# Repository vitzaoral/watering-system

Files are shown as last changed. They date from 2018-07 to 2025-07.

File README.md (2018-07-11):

# Watering system
IoT watering system based on ESP8266 Wemos D1 Mini. Use soil moisture sensors and temperature sensor, data are send to Blynk. Water level is checked by ultrasonic distance measuring module. Water pumps are controller by Blynk application manually, powered with 12V (at least 1A) via mosfet modules.
Project is free to use, coded in C++, created in Visual Code with [PlatfomIO IDE](http://docs.platformio.org/en/latest/ide/vscode.html).

> To build a project, you need to download all the necessary libraries and create the *settings.cpp* file in the src folder:
```c++
// Watering system project settings
struct Settings
{
    const char *ssid = "WIFI ssid";
    const char *password = "WIFI password";
    const char *blynkAuth = "blynkAuth";
};
```

### Currents list:
* [Wemos D1 Mini](https://www.aliexpress.com/item/D1-mini-V2-Mini-NodeMcu-4M-bytes-Lua-WIFI-Internet-of-Things-development-board-based-ESP8266/32681374223.html)
* [6x Soil Moisture Sensor](https://www.aliexpress.com/item/Smart-Electronics-Soil-Moisture-Hygrometer-Detection-Humidity-Sensor-Module-For-arduino-Development-Board-DIY-Robot-Smart/32562744759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)
* [2x 12V water pump](https://www.aliexpress.com/item/DC-12V-Hydroponics-Heating-Mattress-Food-Mdical-Super-Sound-off-Water-Cooling-Cycle-Brushless-Pressure-Boost/32813036499.html)
* [2x IRF520 MOS Driver Module](https://www.aliexpress.com/item/1PCS-0-24V-Top-Mosfet-Button-IRF520-MOS-Driver-Module-For-Arduino-MCU-ARM-Raspberry-pi/32722409551.html)
* [HC-SR04 ultrasonic distance measuring module](https://www.aliexpress.com/item/1pcs-Ultrasonic-Module-HC-SR04-Distance-Measuring-Transducer-Sensor-HC-SR04-HCSR04/32703532280.html)
* [74HC4051 Multiplexer](https://www.aliexpress.com/item/10PCS-LOT-CD4051BE-CD4051-4051BE-4051-DIP16-new-and-original-IC/32807746646.html)
* [GY-BME280-3-3 Temperature/Humidity/Presure sensor](https://www.aliexpress.com/item/1PCS-GY-BME280-3-3-precision-altimeter-atmospheric-pressure-BME280-sensor-module/32767969468.html)
* [7x9cm prototype circuit board](https://www.aliexpress.com/item/MCIGICM-5Pcs-DIY-Prototype-Paper-PCB-Universal-Experiment-Matrix-Circuit-Board-7x9cm-7-9/32350333672.html)
* [Plastic case](https://www.aliexpress.com/item/1-piece-158-90-60mm-IP65-waterproof-plastic-case-with-clear-cover-for-electronic-project-Housing/32812690691.html)
* [Temperature sensor box](https://www.aliexpress.com/item/szomk-plastic-humidity-sensor-project-box-2-pcs-84-27-16mm-diy-wall-mounting-plastic-junction/32586666805.html)

### Schema:
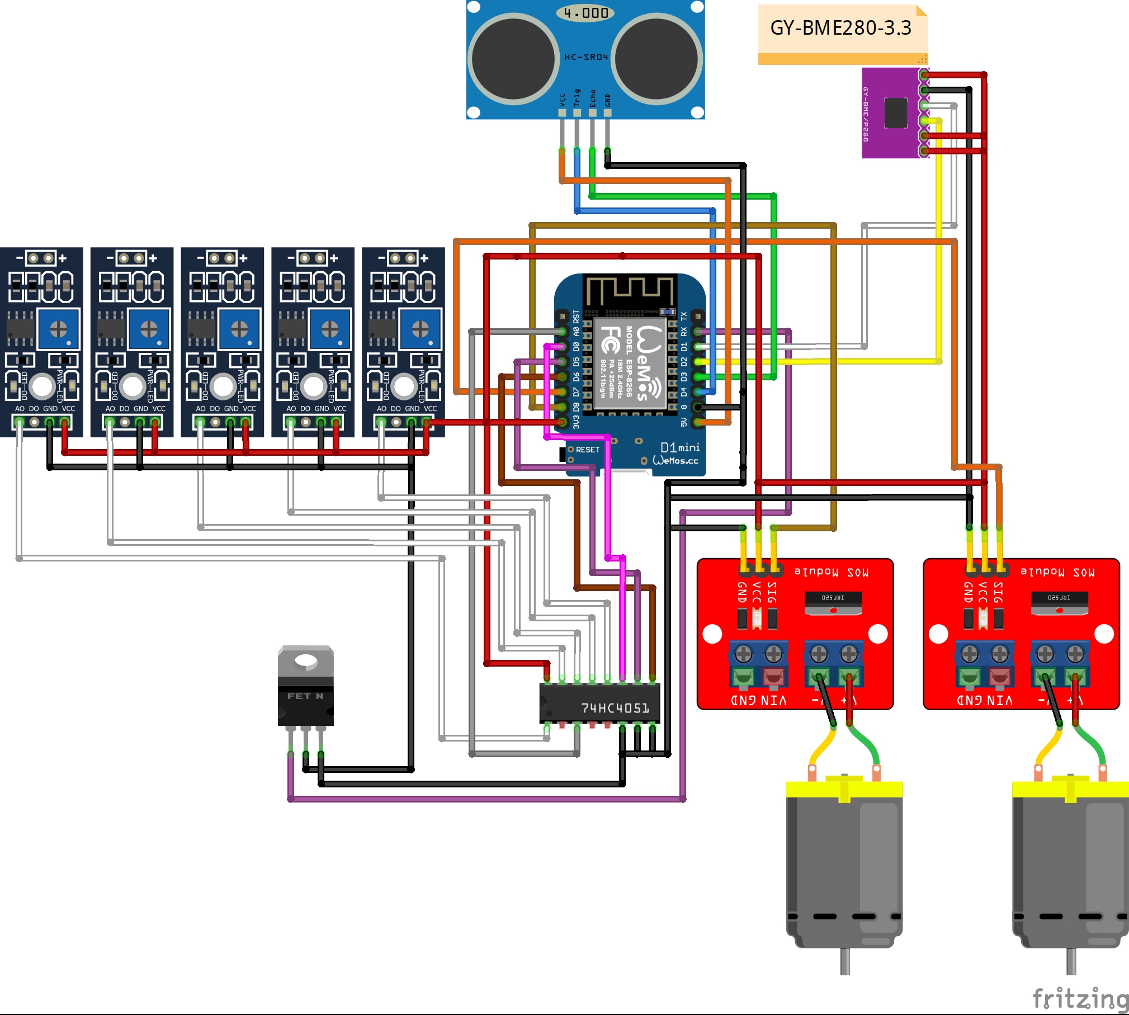
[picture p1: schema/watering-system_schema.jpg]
Schema


### PCB circuit:
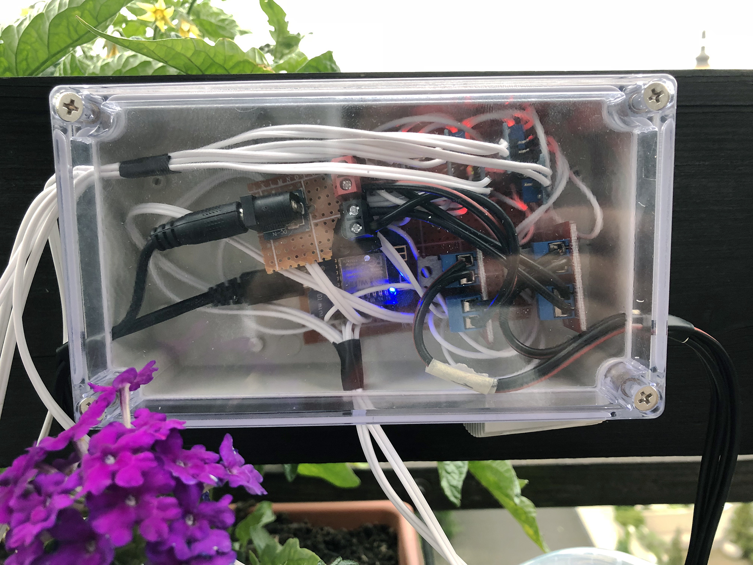
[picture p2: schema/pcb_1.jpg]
PCB 1


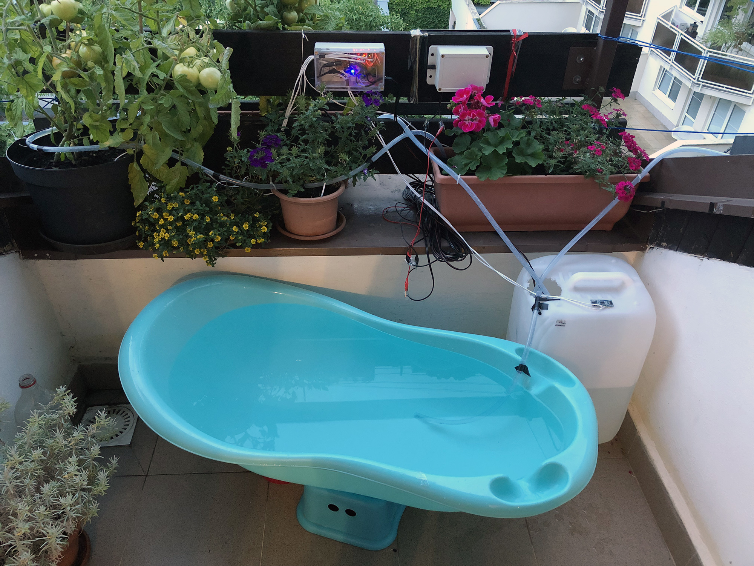
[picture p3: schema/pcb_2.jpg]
PCB 2


### Blynk:
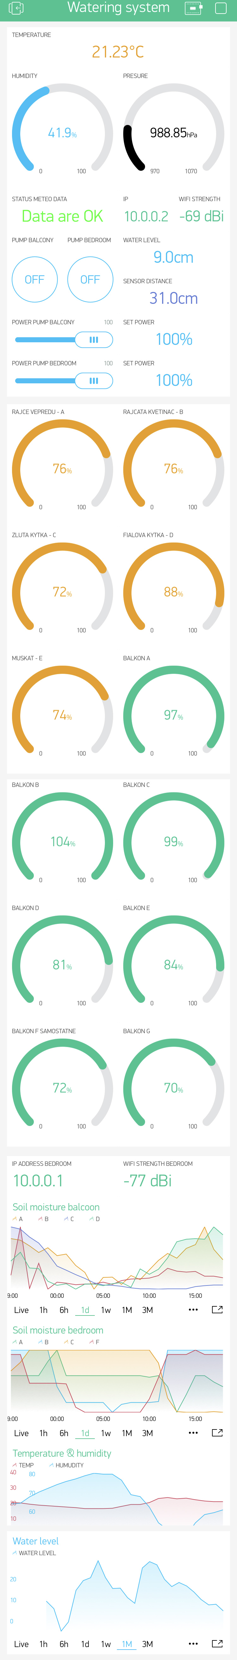
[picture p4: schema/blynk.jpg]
Blynk project


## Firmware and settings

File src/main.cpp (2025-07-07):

#include <Arduino.h>
#include <MeteoData.h>
#include <InternetConnection.h>
#include <Watering.h>
#include <Ticker.h>
#include <EEPROM.h>
#include <time.h>

const long gmtOffset_sec    = 3600;    // standardní posun (UTC+1)
const int  daylightOffset_sec = 3600;  // letní čas navíc
const char* ntpServer       = "pool.ntp.org";

const int sendDataToInternetInterval = 30000;

InternetConnection connection;
MeteoData meteoData;

void sendDataToInternet();
void checkWaterLevel();
Ticker timerSendDataToInternet(sendDataToInternet, sendDataToInternetInterval);
Ticker timerCheckWaterLevel(checkWaterLevel, 4500);

// Connections to APIs are OK
bool apisAreConnected = false;

void initializeInternetConnection()
{
    if (connection.initialize())
    {
        apisAreConnected = connection.initializeBlynk();
    }
}

void checkWaterLevel()
{
    
    if (Watering::checkWaterLevel())
    {
        connection.turnOffPumpButtons();
    }
}

void sendDataToInternet()
{
    if (apisAreConnected)
    {
        bool successBlynk = false;

        WaterLevel waterLevel = Watering::getWaterLevel();
        meteoData.setData();

        successBlynk = connection.sendMeteoDataToBlynk(meteoData, meteoData.dataAreValid());
        successBlynk &= connection.sendWaterLevelToBlynk(waterLevel);

        if (successBlynk)
        {
            Serial.println("Data was sent");
        }
        else
        {
            Serial.println("No internet connection, try initialize connection");
            apisAreConnected = false;
            initializeInternetConnection();
        }
    }
    else
    {
        initializeInternetConnection();
    }
}

void startTimers()
{
    timerSendDataToInternet.start();
    timerCheckWaterLevel.start();
}

void updateTimers()
{
    timerSendDataToInternet.update();
    timerCheckWaterLevel.update();
}

void setup()
{
    Serial.begin(115200);
     delay(100);

    // Two bytes for power of pump1 and pump2
    EEPROM.begin(2);
    Serial.begin(115200);
    delay(100);
    Watering::initialize();
    meteoData.initializeSensors();

    initializeInternetConnection();

    configTime(gmtOffset_sec, daylightOffset_sec, ntpServer);
    Serial.println("SNTP initialized");

    startTimers();
}

void loop()
{
    updateTimers();
    connection.runBlynk();
}

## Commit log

2018-04-16 Project schema
    [schema.fzz, watering-system_schema.fzz]
2018-05-04 Schema, first test code
    [watering-system_schema.fzz]
2018-05-04 Timers and water level measuring
2018-05-04 Blynk pump controll
2018-05-11 Soil Moisture sensors
2018-05-20 Add meteo sensor + send meteo data to Blynk
    [watering-system_schema.fzz]
2018-07-10 Turn on/off soil moisture sensors before/after reading values
    [watering-system_schema.fzz]
2018-07-10 Set pumps power from Blynk
2018-07-10 Comment out turn on/off soil moisture sensor, EEPROM values
2018-11-27 Capacitive soil moisture sensors, saving sensors when sleeping (MOSFET)
2018-11-28 Winter season, commented out water level and soil moisture sensors
2019-09-22 Check water level wan pumps are on. Winter mode.
